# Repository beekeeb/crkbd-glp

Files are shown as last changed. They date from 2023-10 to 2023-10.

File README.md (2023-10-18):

# Corne GLP (Gateron Low Profile)

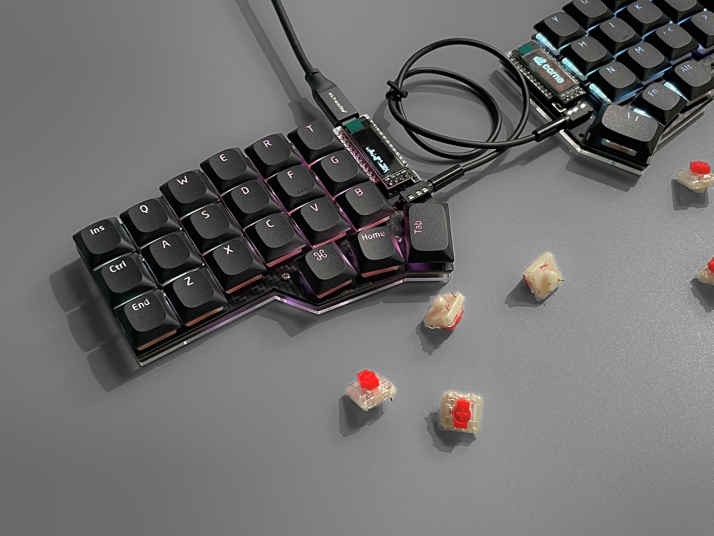
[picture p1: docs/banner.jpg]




The Corne GLP (Gateron Low Profile) is a variant of the Corne keyboard, originally created by [foostan](https://github.com/foostan/crkbd "foostan"). It supports Gateron low-profile key switches (KS-27 and KS-33). The original Corne firmware can be used with this keyboard.

## Photos
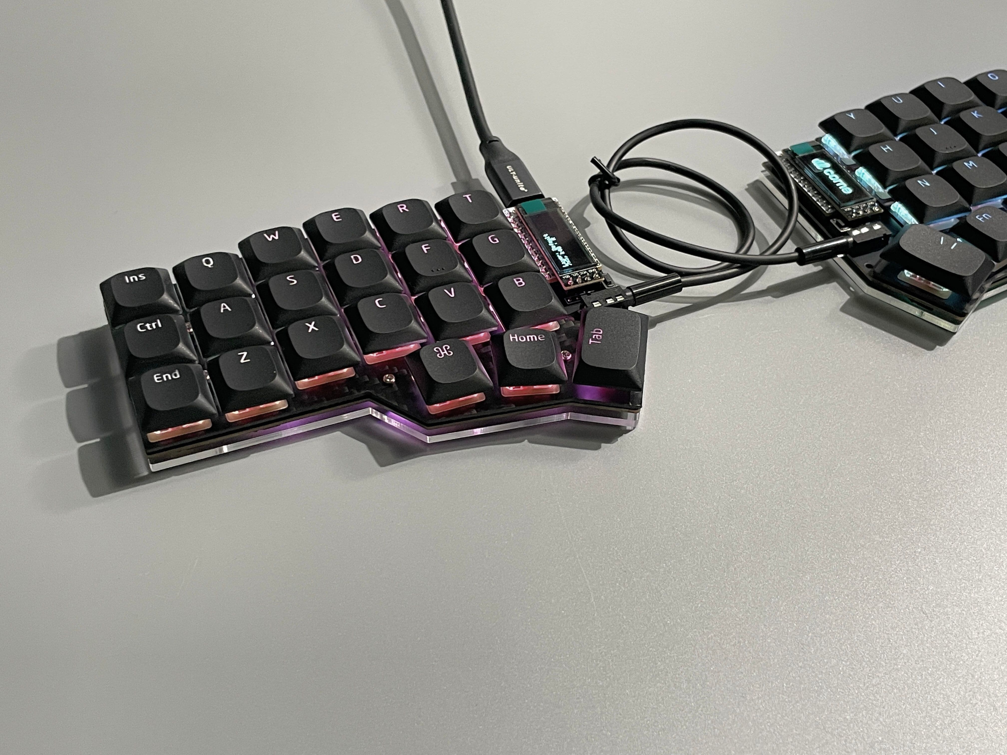
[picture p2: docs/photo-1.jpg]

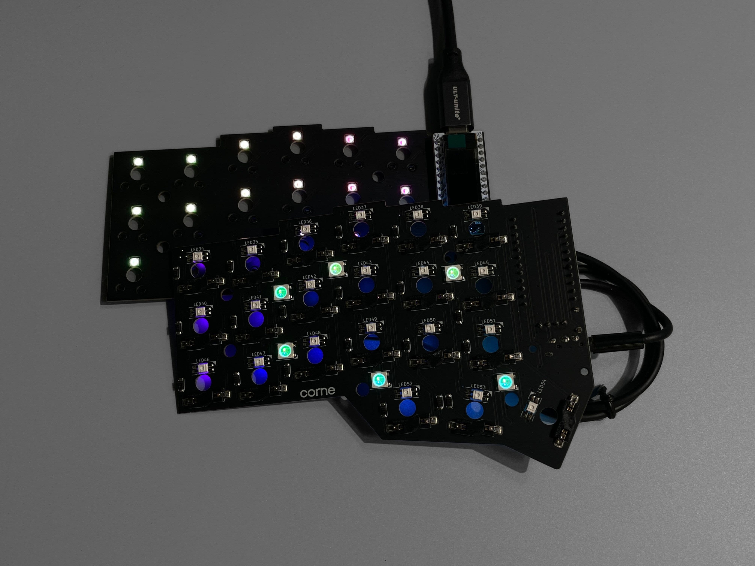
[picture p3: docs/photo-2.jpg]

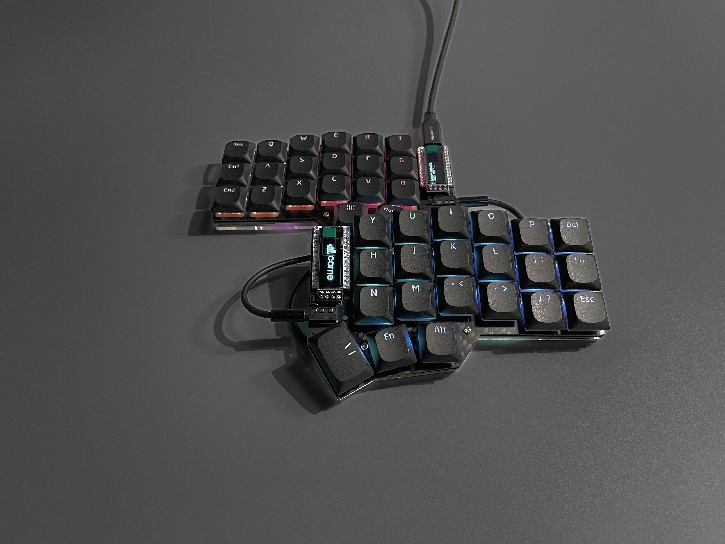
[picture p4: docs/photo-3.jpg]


## Bill of Materials (BOM)
### Required

| Name | Count | Remarks |
|:-|:-|:-|
| PCB | 1 set | |
| Top plate | 2 sheets | 1.2mm thick |
| Bottom plate | 2 sheets | |
| OLED cover | 2 sheets | |
| Pro Micro or equivalent | 2 |  |
| TRRS jack | 2 | |
| Reset switch | 2 | |
| Diodes | 42 | SMD Only (SOD-123 Package) |
| Gateron Low Profile Hotswap Sockets | 42 |  |
| Key switches | 42 | Only compatible with Gateron KS-33 / KS-27 |
| Keycaps | 42 pieces | 1u 40 pcs, 1.5u 2 pcs [Keycaps Comparison](https://showcase.beekeeb.com/the-keycaps-of-gateron-low-profile-key-switches-and-kailh-choc-v1-key-switch/) |
| Spacer M2 5mm | 10 pieces | For Case assembly |
| Spacer M2 9mm | 4 pieces | For OLED cover |
| Screw M2 4mm | 28 screws | |
| Rubber feet | 8 pieces | |
| TRRS (4 poles) cable | 1 |  |
| Micro USB or USB-C cable | 1 | Avoid charge-only cables |

### Optional

| Name | Count | Remarks |
|:-|:-|:-|
| OLED module | 2 | |
| SK6812MINI-E | 42 | LEDs for Backlight |
| WS2812B | 12 | LEDs for Undergrow |
| Microcontroller/OLED Sockets | 1 |  |
| Microcontroller Pins | 48 | Alternative: Diode/Resistor legs |
| OLED Headers | 1 | Soldered to OLED module |

## Plates
It is compatible with Corne v3 top and bottom plates.
* [Corne Top / Bottom Plates](https://github.com/foostan/crkbd/tree/main/plates/pcb)

## Ordering Parts

[DIY kits / Prebuilt Keyboards](https://shop.beekeeb.com/product/corne-glp-kit/) are available at https://beekeeb.shop.

## External Libraries
* [https://github.com/siderakb/key-switches.pretty](https://github.com/siderakb/key-switches.pretty)
* [https://github.com/foostan/kbd](https://github.com/foostan/kbd)

## More Information
* [A great doc about Gateron Low Profile switches writen by Rafael Yumagulov](https://ergonautkb.github.io/docs/switches/gateron-low-profile/)
* [More photo of Corne GLP](https://showcase.beekeeb.com/corne-glp/)
* [Keycaps for Gateron Low Profile Key Switches](https://showcase.beekeeb.com/the-keycaps-of-gateron-low-profile-key-switches-and-kailh-choc-v1-key-switch/)

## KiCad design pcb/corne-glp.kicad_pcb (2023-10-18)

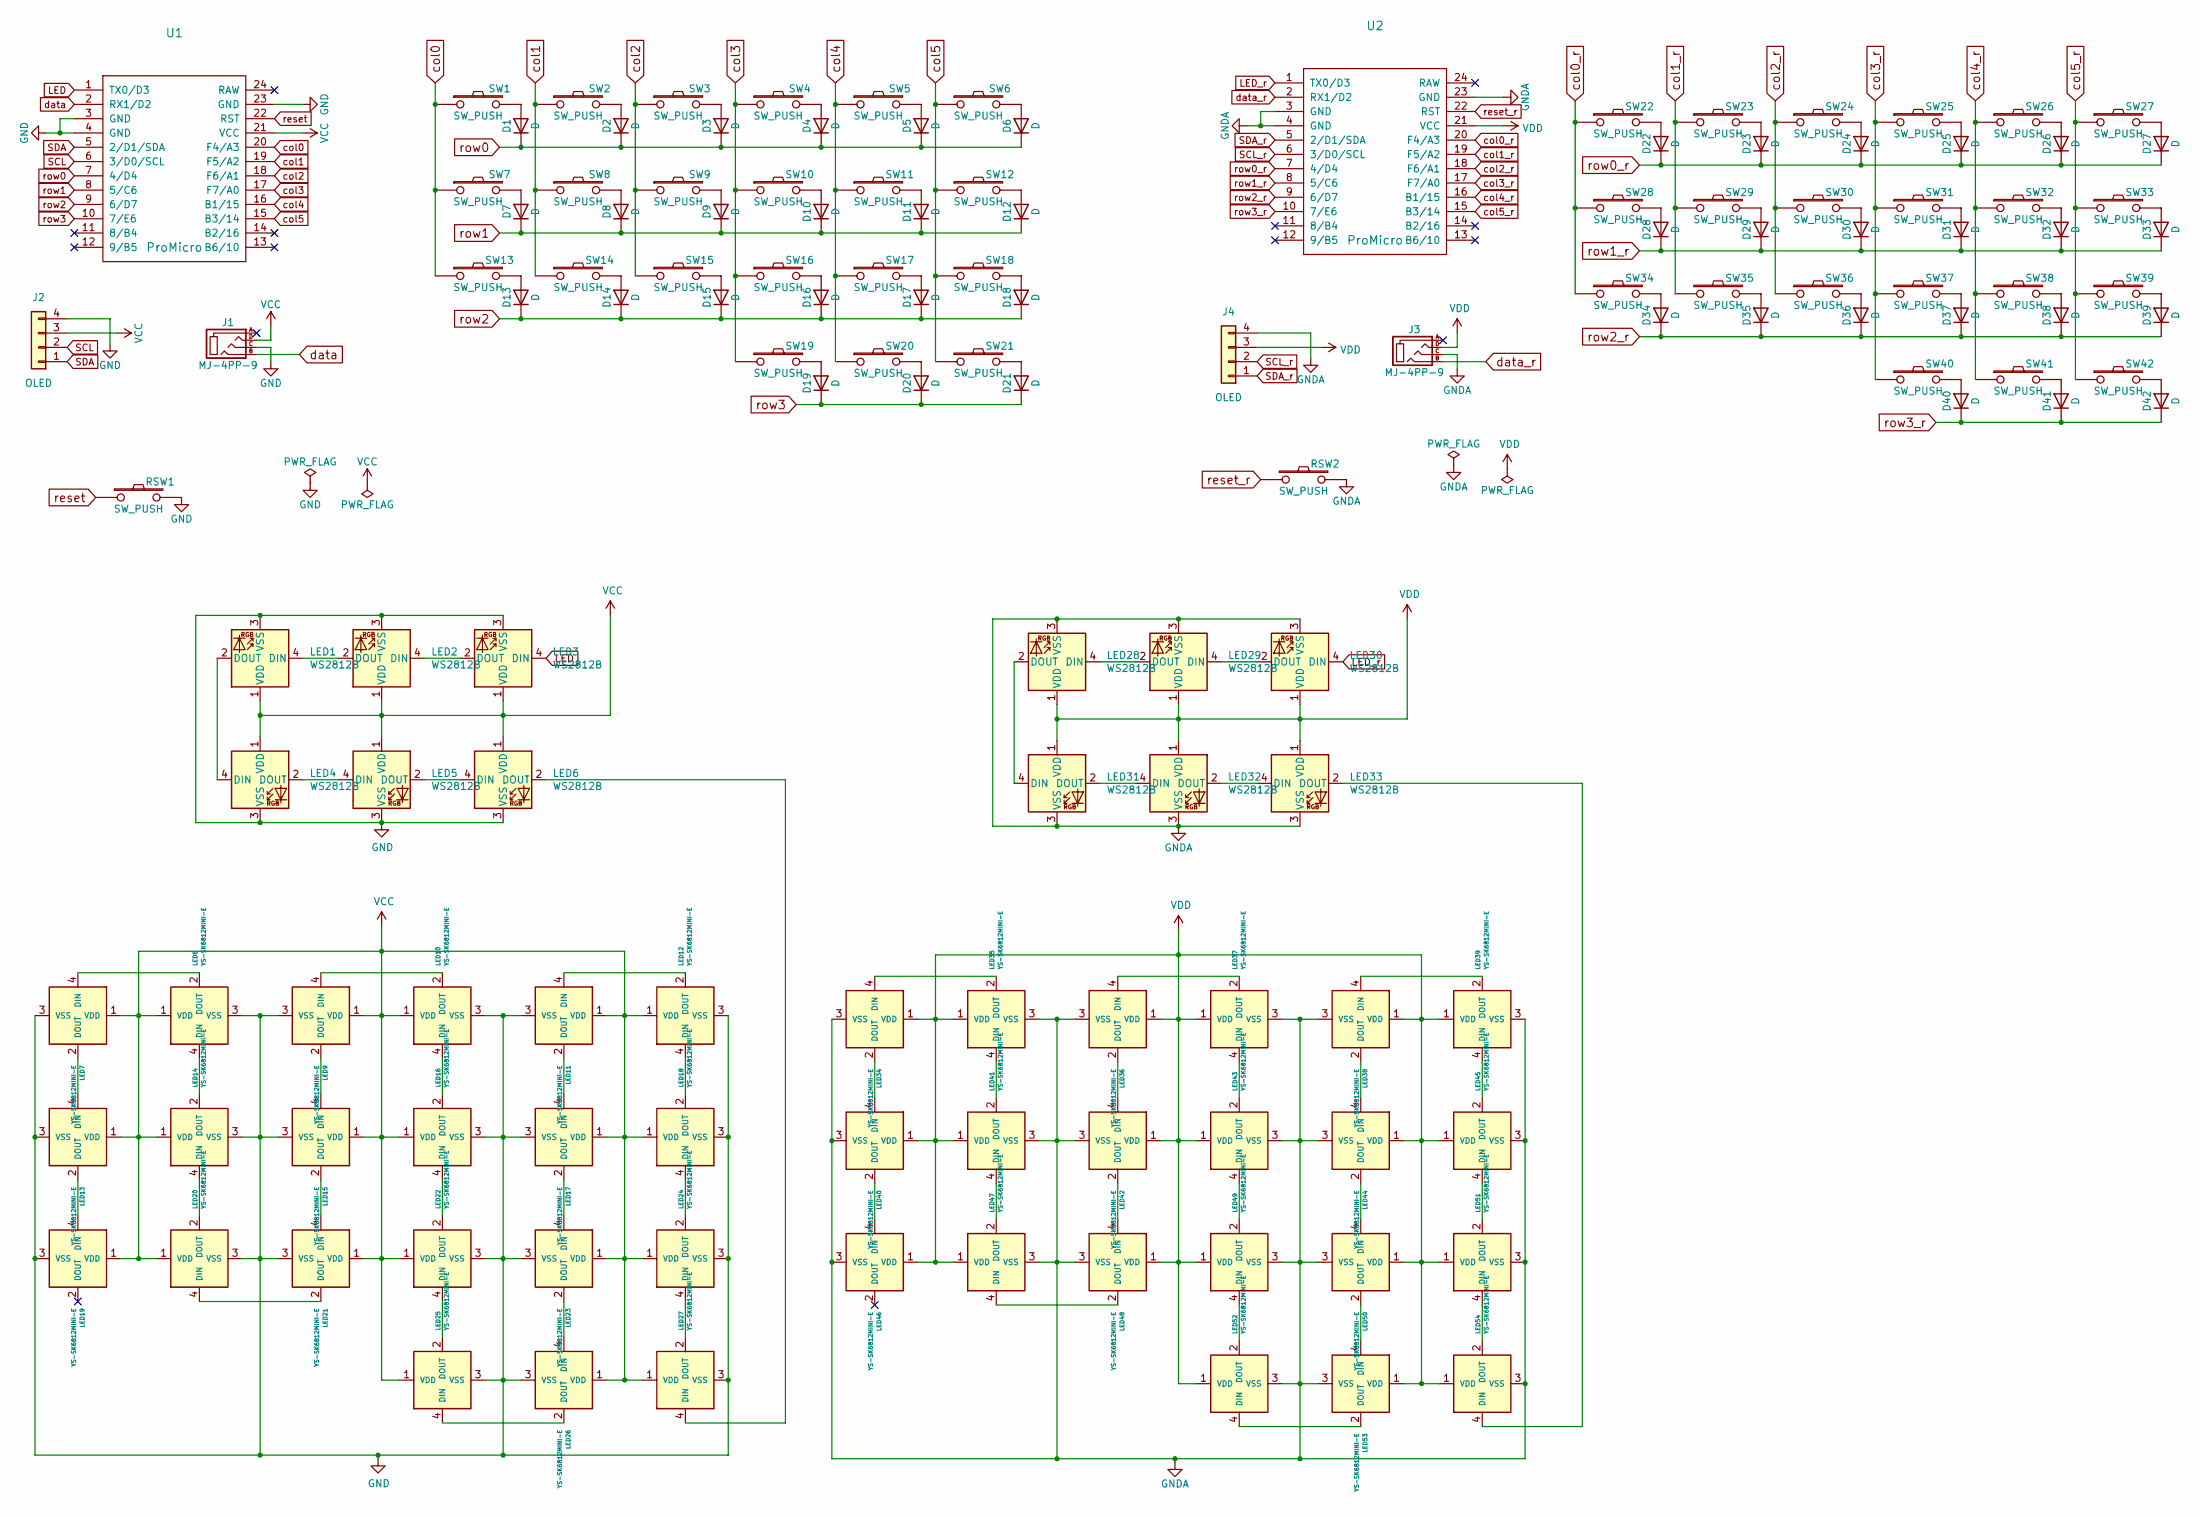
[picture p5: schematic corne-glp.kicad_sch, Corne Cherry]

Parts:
D1, D2, D3, D4, D5, D6, D7, D8, D9, D10, D11, D12, D13, D14, D15, D16, D17, D18, D19, D20, D21, D22, D23, D24, D25, D26, D27, D28, D29, D30, D31, D32, D33, D34, D35, D36, D37, D38, D39, D40, D41, D42: D; D3_SMD_v2
J1, J3: MJ-4PP-9; MJ-4PP-9_1side
J2, J4: OLED; OLED_1side
LED1, LED2, LED3, LED4, LED5, LED6, LED28, LED29, LED30, LED31, LED32, LED33: WS2812B; LED_WS2812B_PLCC4_5.0x5.0mm_P3.2mm
LED7, LED8, LED9, LED10, LED11, LED12, LED13, LED14, LED15, LED16, LED17, LED18, LED19, LED20, LED21, LED22, LED23, LED24, LED25, LED26, LED27, LED34, LED35, LED36, LED37, LED38, LED39, LED40, LED41, LED42, LED43, LED44, LED45, LED46, LED47, LED48, LED49, LED50, LED51, LED52, LED53, LED54: YS-SK6812MINI-E
RSW1, RSW2: SW_PUSH; ResetSW_1side
SW1, SW2, SW3, SW4, SW5, SW6, SW7, SW8, SW9, SW10, SW11, SW12, SW13, SW14, SW15, SW16, SW17, SW18, SW19, SW20, SW22, SW23, SW24, SW25, SW26, SW27, SW28, SW29, SW30, SW31, SW32, SW33, SW34, SW35, SW36, SW37, SW38, SW39, SW40, SW41: SW_PUSH; CherryMX_Hotswap
SW21, SW42: SW_PUSH; CherryMX_Hotswap_1.5u
U1, U2: ProMicro; ProMicro_v3

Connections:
GND: J1.C, J2.4, LED1.3 (VSS), LED2.3 (VSS), LED3.3 (VSS), LED4.3 (VSS), LED5.3 (VSS), LED6.3 (VSS), LED7.3 (VSS), LED8.3 (VSS), LED9.3 (VSS), LED10.3 (VSS), LED11.3 (VSS), LED12.3 (VSS), LED13.3 (VSS), LED14.3 (VSS), LED15.3 (VSS), LED16.3 (VSS), LED17.3 (VSS), LED18.3 (VSS), LED19.3 (VSS), LED20.3 (VSS), LED21.3 (VSS), LED22.3 (VSS), LED23.3 (VSS), LED24.3 (VSS), LED25.3 (VSS), LED26.3 (VSS), LED27.3 (VSS), RSW1.2, U1.3 (GND), U1.4 (GND), U1.23 (GND)
LED: LED3.4 (DIN), U1.1 (TX0/D3)
LED_r: LED30.4 (DIN), U2.1 (TX0/D3)
unnamed: D1.2 (A), SW1.2
unnamed: D2.2 (A), SW2.2
unnamed: D3.2 (A), SW3.2
unnamed: D4.2 (A), SW4.2
unnamed: D5.2 (A), SW5.2
unnamed: D6.2 (A), SW6.2
unnamed: D7.2 (A), SW7.2
unnamed: D8.2 (A), SW8.2
unnamed: D9.2 (A), SW9.2
unnamed: D10.2 (A), SW10.2
unnamed: D11.2 (A), SW11.2
unnamed: D12.2 (A), SW12.2
unnamed: D13.2 (A), SW13.2
unnamed: D14.2 (A), SW14.2
unnamed: D15.2 (A), SW15.2
unnamed: D16.2 (A), SW16.2
unnamed: D17.2 (A), SW17.2
unnamed: D18.2 (A), SW18.2
unnamed: D19.2 (A), SW19.2
unnamed: D20.2 (A), SW20.2
unnamed: D21.2 (A), SW21.2
unnamed: D22.2 (A), SW22.2
unnamed: D23.2 (A), SW23.2
unnamed: D24.2 (A), SW24.2
unnamed: D25.2 (A), SW25.2
unnamed: D26.2 (A), SW26.2
unnamed: D27.2 (A), SW27.2
unnamed: D28.2 (A), SW28.2
unnamed: D29.2 (A), SW29.2
unnamed: D30.2 (A), SW30.2
unnamed: D31.2 (A), SW31.2
unnamed: D32.2 (A), SW32.2
unnamed: D33.2 (A), SW33.2
unnamed: D34.2 (A), SW34.2
unnamed: D35.2 (A), SW35.2
unnamed: D36.2 (A), SW36.2
unnamed: D37.2 (A), SW37.2
unnamed: D38.2 (A), SW38.2
unnamed: D39.2 (A), SW39.2
unnamed: D40.2 (A), SW40.2
unnamed: D41.2 (A), SW41.2
unnamed: D42.2 (A), SW42.2
unnamed: LED1.2 (DOUT), LED4.4 (DIN)
unnamed: LED1.4 (DIN), LED2.2 (DOUT)
unnamed: LED2.4 (DIN), LED3.2 (DOUT)
unnamed: LED4.2 (DOUT), LED5.4 (DIN)
unnamed: LED5.2 (DOUT), LED6.4 (DIN)
unnamed: LED7.4 (DIN), LED8.2 (DOUT)
unnamed: LED9.4 (DIN), LED10.2 (DOUT)
unnamed: LED10.4 (DIN), LED16.2 (DOUT)
unnamed: LED11.2 (DOUT), LED17.4 (DIN)
unnamed: LED11.4 (DIN), LED12.2 (DOUT)
unnamed: LED12.4 (DIN), LED18.2 (DOUT)
unnamed: LED13.2 (DOUT), LED19.4 (DIN)
unnamed: LED7.2 (DOUT), LED13.4 (DIN)
unnamed: LED8.4 (DIN), LED14.2 (DOUT)
unnamed: LED14.4 (DIN), LED20.2 (DOUT)
unnamed: LED15.2 (DOUT), LED21.4 (DIN)
unnamed: LED9.2 (DOUT), LED15.4 (DIN)
unnamed: LED16.4 (DIN), LED22.2 (DOUT)
unnamed: LED17.2 (DOUT), LED23.4 (DIN)
unnamed: LED18.4 (DIN), LED24.2 (DOUT)
unnamed: LED20.4 (DIN), LED21.2 (DOUT)
unnamed: LED22.4 (DIN), LED25.2 (DOUT)
unnamed: LED23.2 (DOUT), LED26.4 (DIN)
unnamed: LED24.4 (DIN), LED27.2 (DOUT)
unnamed: LED25.4 (DIN), LED26.2 (DOUT)
unnamed: LED6.2 (DOUT), LED27.4 (DIN)
unnamed: LED28.2 (DOUT), LED31.4 (DIN)
unnamed: LED28.4 (DIN), LED29.2 (DOUT)
unnamed: LED29.4 (DIN), LED30.2 (DOUT)
unnamed: LED31.2 (DOUT), LED32.4 (DIN)
unnamed: LED32.2 (DOUT), LED33.4 (DIN)
unnamed: LED33.2 (DOUT), LED54.4 (DIN)
unnamed: LED34.2 (DOUT), LED40.4 (DIN)
unnamed: LED34.4 (DIN), LED35.2 (DOUT)
unnamed: LED35.4 (DIN), LED41.2 (DOUT)
unnamed: LED36.2 (DOUT), LED42.4 (DIN)
unnamed: LED36.4 (DIN), LED37.2 (DOUT)
unnamed: LED37.4 (DIN), LED43.2 (DOUT)
unnamed: LED38.2 (DOUT), LED44.4 (DIN)
unnamed: LED38.4 (DIN), LED39.2 (DOUT)
unnamed: LED39.4 (DIN), LED45.2 (DOUT)
unnamed: LED40.2 (DOUT), LED46.4 (DIN)
unnamed: LED41.4 (DIN), LED47.2 (DOUT)
unnamed: LED42.2 (DOUT), LED48.4 (DIN)
unnamed: LED43.4 (DIN), LED49.2 (DOUT)
unnamed: LED44.2 (DOUT), LED50.4 (DIN)
unnamed: LED45.4 (DIN), LED51.2 (DOUT)
unnamed: LED47.4 (DIN), LED48.2 (DOUT)
unnamed: LED49.4 (DIN), LED52.2 (DOUT)
unnamed: LED50.2 (DOUT), LED53.4 (DIN)
unnamed: LED51.4 (DIN), LED54.2 (DOUT)
unnamed: LED52.4 (DIN), LED53.2 (DOUT)
SCL: J2.2, U1.6 (3/D0/SCL)
SDA: J2.1, U1.5 (2/D1/SDA)
VCC: J1.D, J2.3, LED1.1 (VDD), LED2.1 (VDD), LED3.1 (VDD), LED4.1 (VDD), LED5.1 (VDD), LED6.1 (VDD), LED7.1 (VDD), LED8.1 (VDD), LED9.1 (VDD), LED10.1 (VDD), LED11.1 (VDD), LED12.1 (VDD), LED13.1 (VDD), LED14.1 (VDD), LED15.1 (VDD), LED16.1 (VDD), LED17.1 (VDD), LED18.1 (VDD), LED19.1 (VDD), LED20.1 (VDD), LED21.1 (VDD), LED22.1 (VDD), LED23.1 (VDD), LED24.1 (VDD), LED25.1 (VDD), LED26.1 (VDD), LED27.1 (VDD), U1.21 (VCC)
col0: SW1.1, SW7.1, SW13.1, U1.20 (F4/A3)
col0_r: SW22.1, SW28.1, SW34.1, U2.20 (F4/A3)
col1: SW2.1, SW8.1, SW14.1, U1.19 (F5/A2)
col1_r: SW23.1, SW29.1, SW35.1, U2.19 (F5/A2)
col2: SW3.1, SW9.1, SW15.1, U1.18 (F6/A1)
col2_r: SW24.1, SW30.1, SW36.1, U2.18 (F6/A1)
col3: SW4.1, SW10.1, SW16.1, SW19.1, U1.17 (F7/A0)
col3_r: SW25.1, SW31.1, SW37.1, SW40.1, U2.17 (F7/A0)
col4: SW5.1, SW11.1, SW17.1, SW20.1, U1.16 (B1/15)
col4_r: SW26.1, SW32.1, SW38.1, SW41.1, U2.16 (B1/15)
col5: SW6.1, SW12.1, SW18.1, SW21.1, U1.15 (B3/14)
col5_r: SW27.1, SW33.1, SW39.1, SW42.1, U2.15 (B3/14)
data: J1.B, U1.2 (RX1/D2)
data_r: J3.B, U2.2 (RX1/D2)
reset: RSW1.1, U1.22 (RST)
reset_r: RSW2.1, U2.22 (RST)
row0: D1.1 (K), D2.1 (K), D3.1 (K), D4.1 (K), D5.1 (K), D6.1 (K), U1.7 (4/D4)
row0_r: D22.1 (K), D23.1 (K), D24.1 (K), D25.1 (K), D26.1 (K), D27.1 (K), U2.7 (4/D4)
row1: D7.1 (K), D8.1 (K), D9.1 (K), D10.1 (K), D11.1 (K), D12.1 (K), U1.8 (5/C6)
row1_r: D28.1 (K), D29.1 (K), D30.1 (K), D31.1 (K), D32.1 (K), D33.1 (K), U2.8 (5/C6)
row2: D13.1 (K), D14.1 (K), D15.1 (K), D16.1 (K), D17.1 (K), D18.1 (K), U1.9 (6/D7)
row2_r: D34.1 (K), D35.1 (K), D36.1 (K), D37.1 (K), D38.1 (K), D39.1 (K), U2.9 (6/D7)
row3: D19.1 (K), D20.1 (K), D21.1 (K), U1.10 (7/E6)
row3_r: D40.1 (K), D41.1 (K), D42.1 (K), U2.10 (7/E6)

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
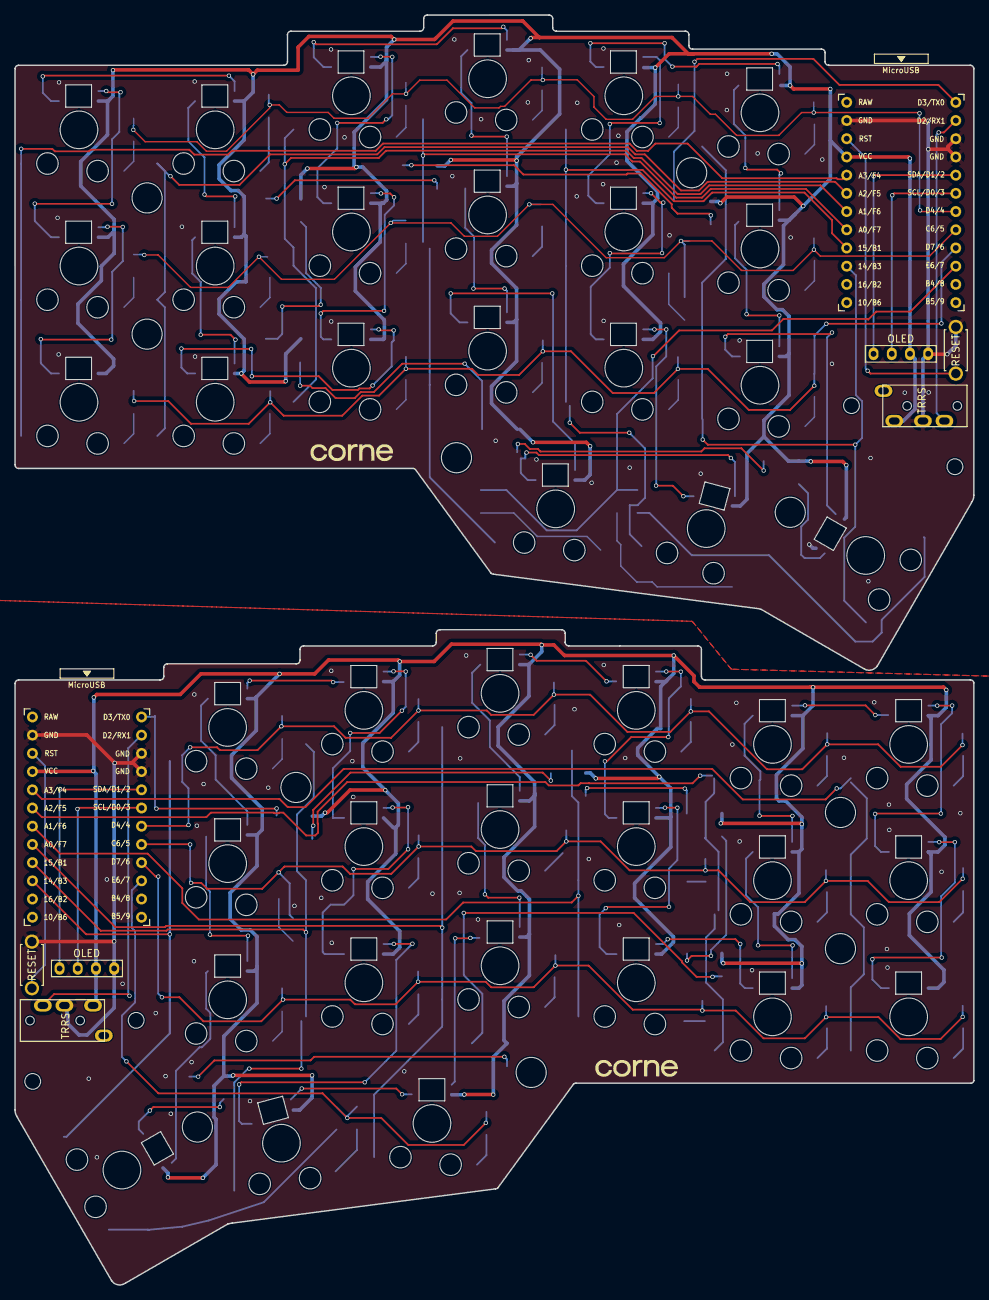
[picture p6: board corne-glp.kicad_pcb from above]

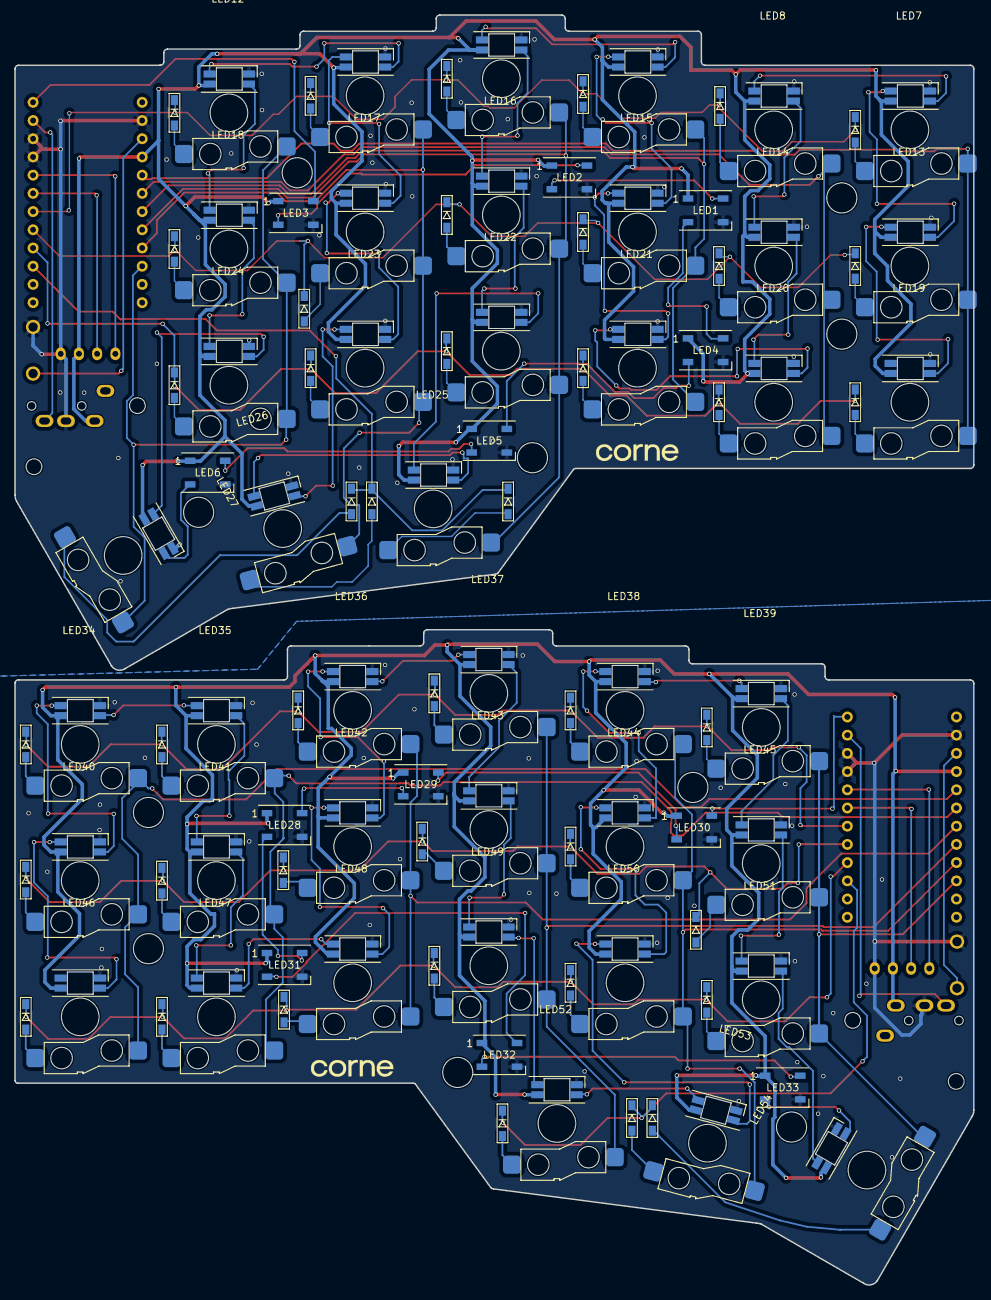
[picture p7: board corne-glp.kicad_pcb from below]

Board: 2 copper layers, 133.8 x 177.1 mm, 160 parts (103 on the bottom side), 128 nets.

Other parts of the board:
h1, h3, h4, h5, h6, h7, h8, h9, h10, h11, h12, h13, h14, h15: Val**; M2_HOLE_v2

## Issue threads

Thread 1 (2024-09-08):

Files gerber for production?

gargullia, 2024-09-08:
Hi. I think it would be a good idea to make files for productions. For JLCPCB and NextPCB producers

cyb3rkun, 2024-10-12:
not that I disagree, but couldn't you just generate them in KiCad?

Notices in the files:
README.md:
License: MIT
